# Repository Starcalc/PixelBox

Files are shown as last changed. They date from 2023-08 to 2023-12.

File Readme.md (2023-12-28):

# Pixelbox Firmware
-----

## About
Shows effects on different kind of models created with WS2812b-Stripes. The models can be simple stripes oder any rectangular shape. The configuration is done via a config.json and can be controlled via MQTT.

## Configuration
Place the configured config.json in the subdirectory "data/homie" and upload it to the device.

Sample config.json:
```json
{
"name": "nameofdevice",
"device_id": "idofdevice",
"wifi": {
"ssid": "YOURSSID",
"password": "YOURWIFIPASS"
},
"mqtt": {
"host": "your.mqtt.server",
"port": 1883,
"auth": false
},
"ota": {
"enabled": true
},
"settings": {
    "NEOPIXEL_MATRIX_NUM_ROWS": 8,
    "NEOPIXEL_MATRIX_NUM_COLUMNS": 8,
    "PIN_NEOPIXEL_MATRIX": "D2",
    "NEO_MATRIX_CONFIGURATION": "NEO_MATRIX_BOTTOM | NEO_MATRIX_RIGHT | NEO_MATRIX_ROWS | NEO_MATRIX_ZIGZAG",
    "NEO_PERMUTATION": "NEO_GRB",
    "NEO_SPEED": "NEO_KHZ800"
  }
}
```

The "settings"-part is to be configured like the Adafruit Neomatrix-Library.

PIN_NEOPIXEL_MATRIX: Which PIN the pixel data port is connected to. If you're using the ESP8266, remember NOT to use D4, as this PIN is also connected to the blue LED of the chip.

NEO_MATRIX_CONFIGURATION: The first pixel must be at one of the four corners; which corner is indicated by OR'ing either NEO_MATRIX_TOP or NEO_MATRIX_BOTTOM to either NEO_MATRIX_LEFT or NEO_MATRIX_RIGHT. The row/column arrangement is indicated by further OR'ing either NEO_MATRIX_COLUMNS or NEO_MATRIX_ROWS to either NEO_MATRIX_PROGRESSIVE or NEO_MATRIX_ZIGZAG. 

NEO_PERMUTATION: Indicate the type of LED pixels being used.

## Configuration within source code

In PixelBox.cpp on line somewhere around 35, you can configure the WIFI-Connection-capabilities of the PixelBox. If you `#define NOWIFI`, the box will rotate through some effects and will repeat them forever. 

```
#define NOWIFI // Disable WIFI alltogether
```

If you don't `#define` it (e.g. comment the line out), you can configure your WIFI and MQTT-Server in the config.json. The PixelBox will connect there and you can set the new effect by publishing to its MQTT-path.

Change the values for MQTT_HOST and "idofdevice" to the corresponding values and you can control your PixelBox via MQTT. You can easily add MQTT-commands in your [Home Assistant](https://www.home-assistant.io/) or [Node RED](https://nodered.org/).

```
mosquitto_pub -h MQTT_HOST -t "homie/idofdevice/pixel/effect/set" -m "rainbow"
```

## Features
### LED 8x8 Field
|Topic |Descriptions  |settable |Values |
|---|---|:---:|---|
|homie/`device_id`/pixel/color|Range property to set the effects colors 1 & 2 see: [effect colors](#effect-colors)|yes|Color as uint32_t see [Color](#color)|
|homie/`device_id`/pixel/brightness|Sets the brightness of the pixel strip|yes|possible values: 0 - 255|
|homie/`device_id`/pixel/effect|Set effect|yes|see: [effects](#effects)|

## Effects
### text
If the attached strips construct a rectangle, you can send scrolling text to it. The optional parameter defines the speed (interval between updates in ms) and the color.

Example: `mosquitto_pub -h HOST -t "homie/device_id/pixel/effect/set" -m "text|Hello world|100|#FF0000"`

### scanner
Shows the moving larson scanner eye known form *Battlestar Galactica* and *Knight Rider*. <!-- The used effect color can be specified by *color_0* -->

### rocket
Shows the moving larson scanner with only a trail (not an eye like `scanner`). <!-- The used effect color can be specified by *color_0* -->

### fire
If on a rectangle, shows a fireplace style fire<!--, otherwise lets all LEDs flicker somehow firelike -->.

### snow
If on a rectangle, lets snow slowly fall down from above. It melts somehow if it reaches the bottom.
<!--* **larsonspiral**
This is the same scanner then the randomscanner above but uses a spiral pattern -->
<!-- * **randomscanner**
Shows the moving larson scanner eye known form *Battlestar Galactica* and *Knight Rider*. Uses some randomness to change directions and cycles through colours. -->

### rainbowcycle
Shows a cycling rainbow on the LED strip

### theaterchase
Shows an color chasing LED strip.
<!-- You can specify the color by set *color_0* and *color_1* -->

### fade
Fades from effect color_0 to effect_color_1

<!--
### randomfade
Fades thru an alternating color pattern on all pixels with the same color.
### randomfade|40
Fades thru an alternating color pattern on all pixels with different color.
### random
Shows random static colors on all pixels differently.
-->

### smooth
Smooth changing effect.

### plasma
The all famous plasma effect known from many 8bit-Demos from the '80s and '90s.

### plasma4
The all famous plasma effect known from many 8bit-Demos from the '80s and '90s. A bit different with four calculated circles.

### heartbeat
Flashes the strip in red "a bit" like a heartbeat

### heart
On a 8x8 pixel matrix, shows a heart moving from top to bottom

### ball
Lets a ball "jump" multiple times, decreasing height. Works best on a vertical mounted strip.

### stripes
Like the `theaterchase`, but using bigger stripes following each other

<!--
### striped
?? Not working ?? -->
<!--
### stars
Multiple falling stars. Not fully implemented yet. -->
### gameoflife
Conway's game of life, only really works on a matrix

### gameoflifec
Conway's game of life like above, but colors new cells in green, dying cells in red.

### gameoflifed
Conway's game of life like above, but dims new cells (red) slowly to white if they live longer.

### snake
Auto-Play a game of snake, only really works on a matrix.

### sparkle
Randomly lets sparkles appear, looks nice on any kind of attached strip. Multiple optional parameters can be given:
interval in ms, CreationTimeout in ms, Increment as Integer, Decrement as Float

Examples:

#### static noise

`mosquitto_pub -h HOST -t "homie/device_id/pixel/effect/set" -m "sparke|1|20000|0.98"`

#### melting snowflakes

`mosquitto_pub -h HOST -t "homie/device_id/pixel/effect/set" -m "sparke|400|2|0.995"`

#### disco flash

`mosquitto_pub -h HOST -t "homie/device_id/pixel/effect/set" -m "sparke|1|3|0.1"`

#### calm

`mosquitto_pub -h HOST -t "homie/device_id/pixel/effect/set" -m "sparkle|100|1.05|0.9"`

### interval

<!-- TODO: Publish as a non-effect, but as a parameter like "brightness" -->
Changes the interval with the given parameter
`mosquitto_pub -h HOST -t "homie/device_id/pixel/effect/set" -m "100"`

### none
Stop all effects

## Effect colors
You can set to different effect colors
* *color_0* (default R: 255, G: 0  B: 0)
* *color_1* (default R: 0, G: 0  B: 255)

The effect color has to be set after the effect. <!-- Is this still true? -->
###### Example:
1. `homie/device_id/pixel/effect -m "fade"`
2. `homie/device_id/strip/color_0/set -m "255"`
3. `homie/device_id/strip/color_1/set -m "10216992"`

##### color_0
This color will be used for the following effects:
* *scanner*
* *theaterchase*
* *fade*

##### color_1
This color will be used for the following effects:
* *theaterchase*
* *fade*

## How to add another effect

The *correct* way would be to create your own Class which inherits NewMatrix(), but I guess you could just change the NewMatrix.hpp and NewMatrix.h for yourself.

* Add your string which triggers the effect to `onSetEffect()` in `PixelBox.cpp` like this:
```
  else if (command == "youreffect")
    NeoPixelMatrix.YourEffect();
  }
```
* Add your "PATTERN"-Definition in `NewMatrix.h` and increase the `LASTNEWMATRIX_PATTERN`-Counter
```
#define PATTERN_YOUREFFECT      (PATTERN_SNAKE + 13)
#define LAST_NEWMATRIX_PATTERN  (PATTERN_SNAKE + 13)
```
* Add your Update()-Call to the generic Update()-Call in `NewMatrix.hpp`:
```
case PATTERN_YOUREFFECT:
    YourPatternUpdate();
    break;
```
* Add the definition of your Pattern-Setup and Pattern-Update-Routines in `NewMatrix.h`:
```
void YourEffect();
void YourEffectUpdate();
```
* Add the code which executes your effect to `NewMatrix.hpp`:
```
void NewMatrix::YourEffect() {
    // Set up your effect, e.g. clear or define variables
    clear();
    show();
}

void NewMatrix::YourEffectUpdate() {
    show();
    lastUpdate = millis();
}
```

## List of necessary materials

Here's what you'll need:
* ESP8266 (I use the WEMOS D1 mini R2, you can easily find it on chinese selling websites)
* WS2812B-Strips with 30 LEDs/m. You'll need 64 pixels for a 8x8 Pixelbox, so at least 3 meters.
* Small wires
* Micro-USB-Power supply (5V, preferably 2A)
* Soldering equipment
* poplar wood, 4mm strong
* frosted plastic, 3-4mm strong, preferably white
* Micro-USB-Cable to connect to your PC (to transfer the initial program)

## How to build the casing

In the directory "Lasercutter" are the samples you can use for your lasercutter. You'll need one backplane, four sides all made from wood (we used poplar wood), 4mm strong. The cover should be a frosted plastic, 3-4mm strong, preferably white.

For the "pixel" effect itself you'll need to seperate the individual LEDs, so from the "trenner.dxf", you'll need 14 overall. While putting everything together remember to put the small gap in a fashion that you can place the cables, which will be connecting the LED-stripes, into these gaps.

I've added another hole where the first pixel is located to put the cables coming from the ESP8266 inside, that way the ESP8266 can be added on the backside of the pixelbox.

If you want to use a very high brightness with all LEDs showing white, the box itself will pull a lot of current (~2A), which is just about too much for the little LED stripes to handle. You'll notice that the LEDs become more and more orange/brown until the end of the strip. If you add yet another hole somewhere in the middle and add the current only there, you can neglect the effect. Remember than to add not only the "data"-cable to the ESP8266, but the GND as well.

Placing the LED-stripes I can recommend to arrange them in a "zig-zag"-manner, that way the config.json.sample will easily fit and you can add the cables between the stripes easily on one side, than on the other side.

## How to build the software

I recommend using Visual Studio Code. After successful installation, add the extension "PlatformIO" to Visual Studio Code and open the code from this repository. The "platformio.ini" is already configured for an WEMOS D1 mini R2.

If you go to the "PlatformIO"-Icon in Visual Studio Code (it's an alien skull), under "Project Tasks", you'll find these two steps, which you should execute:

* To upload the code itself: d1_mini -> General -> Upload
* To upload the config-File: d1_mini -> Platform -> Upload Filesystem Image

-----
# Thanks

A big shoutout to these people who made this Pixelbox possible:

* https://github.com/ArminJo
* https://github.com/adafruit
* https://github.com/bblanchon
* https://github.com/homieiot
* https://figch.de

And some more people from https://ctdo.de/ which either don't want to be named here or don't have a linkable presence.

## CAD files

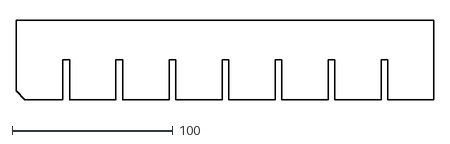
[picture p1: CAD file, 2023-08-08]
Lasercutter/trenner.dxf
259.6 x 49.6

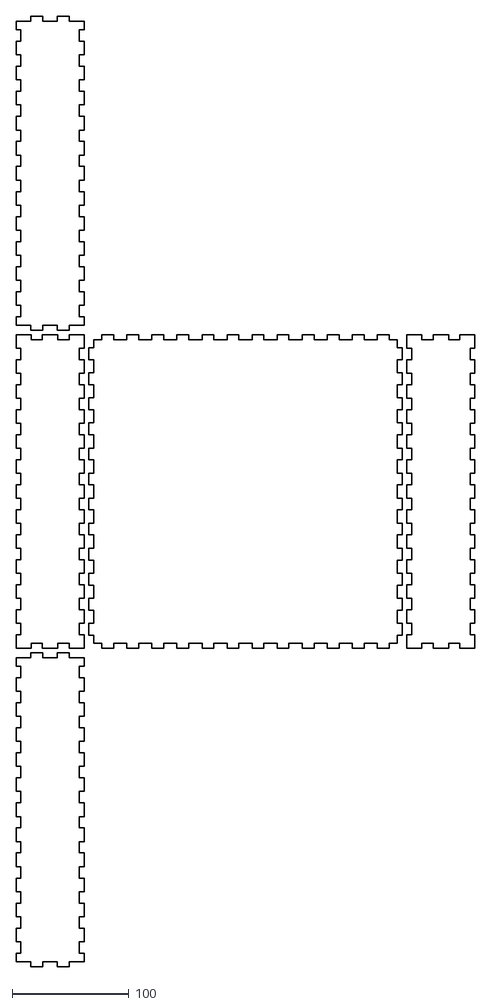
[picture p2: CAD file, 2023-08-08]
Lasercutter/box.dxf
392.6 x 812.6

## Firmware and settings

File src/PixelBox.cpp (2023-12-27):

/*
 *  PixelBox.cpp by Stefan Magerstedt
 *  Effects inspired by Armin Joachimsmeyer
 *  Uses https://github.com/ArminJo/NeoPatterns.
 *
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
 */

#define ENABLE_PATTERNS_FOR_MATRIX_AND_SNAKE_DEMO_HANDLER
#define ENABLE_PATTERNS_FOR_SNAKE_AUTORUN
#define ENABLE_PATTERN_RAINBOW_CYCLE
#define ENABLE_PATTERN_COLOR_WIPE
#define ENABLE_PATTERN_FADE
#define ENABLE_PATTERN_SCANNER_EXTENDED
#define ENABLE_PATTERN_FLASH
#define ENABLE_PATTERN_PROCESS_SELECTIVE
#define ENABLE_PATTERN_STRIPES
#define ENABLE_PATTERN_HEARTBEAT
#define ENABLE_PATTERN_BOUNCING_BALL
#define ENABLE_MATRIX_PATTERN_FIRE
#define ENABLE_MATRIX_PATTERN_SNOW

// #define NOWIFI // Disable WIFI alltogether
// #define APONLY // Disable Homie with Wifi and MQTT, but open an AP with a Web Application

#include <Arduino.h>
#include "NewMatrix.hpp"
#include "Particle.hpp"
#include "Rocket.hpp"
#include <LongUnion.h> // for faster random()
#ifndef NOWIFI
#include <ArduinoOTA.h>
#include "fixWiFi.h"
#include <Homie.h>

#else
#include <Homie/Config.hpp>
HomieInternals::Interface* homieinterface;
#endif


HomieSetting<long> rowSetting("NEOPIXEL_MATRIX_NUM_ROWS", "Rows in the matrix");
HomieSetting<long> colSetting("NEOPIXEL_MATRIX_NUM_COLUMNS", "Columns in the matrix");
HomieSetting<const char*> pinSetting("PIN_NEOPIXEL_MATRIX", "Pin connected");
HomieSetting<const char*> CONFIGURATIONSetting("NEO_MATRIX_CONFIGURATION", "Geometry CONFIGURATION");
HomieSetting<const char*> PERMUTATIONSetting("NEO_PERMUTATION", "RGB Permutation");
HomieSetting<const char*> SPEEDSetting("NEO_SPEED", "Speed of Neopixels NEO_KHZ400 or NEO_KHZ800");



/* 
    NeoPixelMatrix ist eine "NewMatrix"
    NewMatrix:: MatrixSnake:: MatrixNeoPatterns:: MatrixNeoPixel,NeoPatterns :: NeoPixel
    TODO: Alle bisherigen Effekte wieder realisieren
    TODO: Farben einbinden und entsprechend reagieren (z.B. bei Theaterchase)
    TODO: Fontgröße anpassbar machen aufgrund der jeweils genutzten Dimensionen (PROGMEM aller Fonts?!)
    TODO: Weitere Fontgrößen einbauen, in MatrixNeoPixel liegen "nur" die bis 8x8 vor.
          https://www.mikrocontroller.net/topic/54860
          Vielleicht den Font auf das FS ablegen und dann dynamisch nachladen, wenn man die Größe kennt?
          Allerdings nutzen alle Funktionen von MatrixNeoPatterns den PGM-Zugriff, um den Font zu erzeugen
    TODO: Bitmaps z.B. per MQTT erhalten und diese dann darstellen, genau wie die PGM-Varianten. Ggfs.
          muss man hierfür noch eine neue Variante bauen, die analog wie die PGM funktioniert.
*/
NewMatrix NeoPixelMatrix = NewMatrix();
char lastText[1024];
int lastinterval = 40;
uint32_t lasttextcolor = COLOR32_WHITE;
uint8_t lastbrightness = 255;

uint32_t lastUpdateCounter = 0;
uint32_t updateInterval = 1000 * 10; // 1000 * 30 = 30s
uint32_t effectCounter = 0;

bool stopAfterCompletion;
bool backup_stopAfterCompletion;
void StripComplete(NeoPatterns * aLedsPtr) {
// TODO: Wenn nicht gestoppt werden soll, soll der Effekt noch einmal angestoßen werden.
// Den letzten Effekt merken? Inklusive Aufruf? Oder jeden Effekt umschreiben, dass er ewig läuft wie z.B. Text?
  if (stopAfterCompletion)
  {
    // Next effect, repeat, etc.
  } else {
    if (NeoPixelMatrix.ActivePattern == PATTERN_TICKER) {
      NeoPixelMatrix.Ticker(lastText, lasttextcolor, COLOR32_BLACK, lastinterval, DIRECTION_LEFT);
    }
//    Serial.println("Do not stop after completion.");
  }
  return;
}

void MatrixInit()  {
  /* Lesen der Matrix-Parameter aus der config.json */
  uint8_t localpin;
  if (strcmp(pinSetting.get(), "D0") == 0) {
    localpin = D0;
  } else if (strcmp(pinSetting.get(), "D1") == 0) {
    localpin = D1;
  } else if (strcmp(pinSetting.get(), "D2") == 0) {
    localpin = D2;
  } else if (strcmp(pinSetting.get(), "D3") == 0) {
    localpin = D3;
  } else if (strcmp(pinSetting.get(), "D4") == 0) {
    localpin = D4;
  } else if (strcmp(pinSetting.get(), "D5") == 0) {
    localpin = D5;
  } else if (strcmp(pinSetting.get(), "D6") == 0) {
    localpin = D6;
  } else if (strcmp(pinSetting.get(), "D7") == 0) {
    localpin = D7;
  } else if (strcmp(pinSetting.get(), "D8") == 0) {
    localpin = D8;
  } else {
    localpin = atoi(pinSetting.get());
  }

  String confsetting = CONFIGURATIONSetting.get();
  uint8_t geometry = 0;

  Serial.println(confsetting);

// TODO: https://learn.adafruit.com/adafruit-neopixel-uberguide/neomatrix-library
//       "Other formats" mit eigener Geometrie sind möglich, da kann man auch 16bit-Integers
//       übergeben. Wenn man also in der Konfigurationsdatei irgendeinen Parameter hinterlegt,
//       dass es sich um einen Streifen handelt, könnte das wieder gehen.

  if (confsetting.indexOf("NEO_MATRIX_TOP") > -1) { geometry = geometry | NEO_MATRIX_TOP; }
  if (confsetting.indexOf("NEO_MATRIX_BOTTOM") > -1) { geometry = geometry | NEO_MATRIX_BOTTOM; }
  if (confsetting.indexOf("NEO_MATRIX_LEFT") > -1) { geometry = geometry | NEO_MATRIX_LEFT; }
  if (confsetting.indexOf("NEO_MATRIX_RIGHT") > -1) { geometry = geometry | NEO_MATRIX_RIGHT; }
  if (confsetting.indexOf("NEO_MATRIX_CORNER") > -1) { geometry = geometry | NEO_MATRIX_CORNER; }
  if (confsetting.indexOf("NEO_MATRIX_ROWS") > -1) { geometry = geometry | NEO_MATRIX_ROWS; }
  if (confsetting.indexOf("NEO_MATRIX_COLUMNS") > -1) { geometry = geometry | NEO_MATRIX_COLUMNS; }
  if (confsetting.indexOf("NEO_MATRIX_AXIS") > -1) { geometry = geometry | NEO_MATRIX_AXIS; }
  if (confsetting.indexOf("NEO_MATRIX_PROGRESSIVE") > -1) { geometry = geometry | NEO_MATRIX_PROGRESSIVE; }
  if (confsetting.indexOf("NEO_MATRIX_ZIGZAG") > -1) { geometry = geometry | NEO_MATRIX_ZIGZAG; }
  if (confsetting.indexOf("NEO_MATRIX_SEQUENCE") > -1) { geometry = geometry | NEO_MATRIX_SEQUENCE; }
  
  uint8_t permutation = 0;
  if (strcmp(PERMUTATIONSetting.get(), "NEO_RGB") == 0) { permutation = permutation | NEO_RGB; } else
  if (strcmp(PERMUTATIONSetting.get(), "NEO_RBG") == 0) { permutation = permutation | NEO_RBG; } else
  if (strcmp(PERMUTATIONSetting.get(), "NEO_GRB") == 0) { permutation = permutation | NEO_GRB; } else
  if (strcmp(PERMUTATIONSetting.get(), "NEO_GBR") == 0) { permutation = permutation | NEO_GBR; } else
  if (strcmp(PERMUTATIONSetting.get(), "NEO_BRG") == 0) { permutation = permutation | NEO_BRG; } else
  if (strcmp(PERMUTATIONSetting.get(), "NEO_BGR") == 0) { permutation = permutation | NEO_BGR; } else
  if (strcmp(PERMUTATIONSetting.get(), "NEO_WRGB") == 0) { permutation = permutation | NEO_WRGB; } else
  if (strcmp(PERMUTATIONSetting.get(), "NEO_WRBG") == 0) { permutation = permutation | NEO_WRBG; } else
  if (strcmp(PERMUTATIONSetting.get(), "NEO_WGRB") == 0) { permutation = permutation | NEO_WGRB; } else
  if (strcmp(PERMUTATIONSetting.get(), "NEO_WGBR") == 0) { permutation = permutation | NEO_WGBR; } else
  if (strcmp(PERMUTATIONSetting.get(), "NEO_WBRG") == 0) { permutation = permutation | NEO_WBRG; } else
  if (strcmp(PERMUTATIONSetting.get(), "NEO_WBGR") == 0) { permutation = permutation | NEO_WBGR; } else
  if (strcmp(PERMUTATIONSetting.get(), "NEO_RWGB") == 0) { permutation = permutation | NEO_RWGB; } else
  if (strcmp(PERMUTATIONSetting.get(), "NEO_RWBG") == 0) { permutation = permutation | NEO_RWBG; } else
  if (strcmp(PERMUTATIONSetting.get(), "NEO_RGWB") == 0) { permutation = permutation | NEO_RGWB; } else
  if (strcmp(PERMUTATIONSetting.get(), "NEO_RGBW") == 0) { permutation = permutation | NEO_RGBW; } else
  if (strcmp(PERMUTATIONSetting.get(), "NEO_RBWG") == 0) { permutation = permutation | NEO_RBWG; } else
  if (strcmp(PERMUTATIONSetting.get(), "NEO_RBGW") == 0) { permutation = permutation | NEO_RBGW; } else
  if (strcmp(PERMUTATIONSetting.get(), "NEO_GWRB") == 0) { permutation = permutation | NEO_GWRB; } else
  if (strcmp(PERMUTATIONSetting.get(), "NEO_GWBR") == 0) { permutation = permutation | NEO_GWBR; } else
  if (strcmp(PERMUTATIONSetting.get(), "NEO_GRWB") == 0) { permutation = permutation | NEO_GRWB; } else
  if (strcmp(PERMUTATIONSetting.get(), "NEO_GRBW") == 0) { permutation = permutation | NEO_GRBW; } else
  if (strcmp(PERMUTATIONSetting.get(), "NEO_GBWR") == 0) { permutation = permutation | NEO_GBWR; } else
  if (strcmp(PERMUTATIONSetting.get(), "NEO_GBRW") == 0) { permutation = permutation | NEO_GBRW; } else
  if (strcmp(PERMUTATIONSetting.get(), "NEO_BWRG") == 0) { permutation = permutation | NEO_BWRG; } else
  if (strcmp(PERMUTATIONSetting.get(), "NEO_BWGR") == 0) { permutation = permutation | NEO_BWGR; } else
  if (strcmp(PERMUTATIONSetting.get(), "NEO_BRWG") == 0) { permutation = permutation | NEO_BRWG; } else
  if (strcmp(PERMUTATIONSetting.get(), "NEO_BRGW") == 0) { permutation = permutation | NEO_BRGW; } else
  if (strcmp(PERMUTATIONSetting.get(), "NEO_BGWR") == 0) { permutation = permutation | NEO_BGWR; } else
  if (strcmp(PERMUTATIONSetting.get(), "NEO_BGRW") == 0) { permutation = permutation | NEO_BGRW; }

  if (strcmp(SPEEDSetting.get(), "NEO_KHZ400") == 0) { permutation = permutation | NEO_KHZ400; } else
  if (strcmp(SPEEDSetting.get(), "NEO_KHZ800") == 0) { permutation = permutation | NEO_KHZ800; } 

  NeoPixelMatrix.init(colSetting.get(), rowSetting.get(), localpin, geometry, permutation, &StripComplete);
}

#ifndef NOWIFI
HomieNode homieNode("pixel", "pixel", "commands");
#endif

bool onSetReverse(const HomieRange & range, const String & value) {
  NeoPixelMatrix.Reverse();
#ifndef NOWIFI
  homieNode.setProperty("reverse").send(value);
#endif
  return true;
}

bool onSetBrightness(const HomieRange& range, const String& value) {
	long brightness = value.toInt();
	if (brightness < 0 || brightness > 255) {
		return false;
	}
	NeoPixelMatrix.setBrightnessValue(brightness);
#ifndef NOWIFI
	homieNode.setProperty("brightness").send(value);
#endif
	return true;
}

bool is_number(String s)
{
  uint16_t Numbers = 0;
  for(uint16_t i = 0; i < s.length(); i++)
  {
    if (s[i] >= '0' && s[i] <= '9')
    {
      Numbers ++;
    }
  }
  if (Numbers == s.length())
  { return true; } else { return false; }
}

uint32_t parseColor(String value) {
  if (value.charAt(0) == '#') { //solid fill
    String color = value.substring(1);
    int number = (int) strtol( &color[0], NULL, 16);
    // Split them up into r, g, b values
    int r = number >> 16;
    int g = number >> 8 & 0xFF;
    int b = number & 0xFF;
    return COLOR32(r, g, b);
  }
  return 0;
}

bool onSetColor0(const HomieRange& range, const String& value) {
  if (value.charAt(0) == '#') {
    NeoPixelMatrix.SetColor1(parseColor(value));
  } else {
    if (!is_number(value)) return false;
    NeoPixelMatrix.SetColor1(value.toInt());
  }
#ifndef NOWIFI
  homieNode.setProperty("color0").setRange(range).send(value);
#endif
  //homieNode.setProperty("color_" + String(range.index)).send(value);
  return true;
}

bool onSetColor1(const HomieRange& range, const String& value) {
  if (value.charAt(0) == '#') {
    NeoPixelMatrix.SetColor2(parseColor(value));
  } else {
    if (!is_number(value)) return false;
    NeoPixelMatrix.SetColor2(value.toInt());
  }
#ifndef NOWIFI
  homieNode.setProperty("color1").setRange(range).send(value);
#endif
  //homieNode.setProperty("color_" + String(range.index)).send(value);
  return true;
}

/***
 * Effektidee: Zwei farbliche "Masken" (veränderbar) für die Darstellung des Textes. Dabei wird die eine für den
 * Hintergrund genutzt, die andere für den eigentlichen Text. So sind dynamische Regenbogenschriftarten möglich,
 * auch innerhalb eines Buchstabens. Oder sogar schneller wechselnd als der Text? (Mit einem zweiten Interval?)
 * 
 * TODO: Randomscanner, rainbowtext, Colors @ rocket and scanner, fire (for flat stripes like in RGB5m), random, randomfade, stars, moving picture (given by MQTT or UDP or...? - maybe store it on the SPIFFS, if possible)
 * aLedsPtr->Stripes(NeoPatterns::Wheel(tColor), 1, NeoPatterns::Wheel(tColor + 0x80), 2, 2 * aLedsPtr->numPixels(),
                tDuration * 2, (tColor & DIRECTION_DOWN));
***/
bool onSetEffect(const HomieRange& range, const String& value) {
  Serial.println(value);
  LongUnion tRandom;
  tRandom.Long = random();
  uint8_t tColor = tRandom.UBytes[1];
  uint8_t tDuration = ((tRandom.UBytes[1] * (80 - 40)) >> 8) + 40;
  NeoPixelMatrix.OnPatternComplete = &StripComplete;
  stopAfterCompletion = false;
  int validparams = 0;
  int sep = value.indexOf("|");
  String param1, param2, param3, param4;
  String command = value;
  if (sep > 0)
  {
    // Parameter given
    command = value.substring(0, sep);
    String parameters = value.substring(sep + 1);
    param1 = parameters;
    validparams = 1;
    int sep2 = parameters.indexOf("|");
    if (sep2 > 0) {
      // Es gibt mindestens zwei Parameter
      param1 = parameters.substring(0, sep2);
      parameters = parameters.substring(sep2 + 1);
      param2 = parameters;
      validparams = 2;
      int sep3 = parameters.indexOf("|");
      if (sep3 > 0)
      {
        // Es gibt mindestens drei Parameter
        param2 = parameters.substring(0, sep3);
        parameters = parameters.substring(sep3 + 1);
        param3 = parameters;
        validparams = 3;
        int sep4 = parameters.indexOf("|");
        if (sep4 > 0)
        {
          // Es gibt mindestens vier Parameter
          param3 = parameters.substring(0, sep4);
          param4 = parameters.substring(sep4 + 1);
          validparams = 4;
        }
      }
    }
  }
	if (command == "text") {
    String stext;
    int interval = 40;
    uint32_t textcolor = COLOR32_WHITE;
    switch (validparams) {
          case 0:
            stext = "(No text given)";
            break;
          case 1:
            stext = param1;
            break;
          case 2:
            stext = param1;
            interval = param2.toInt();
            break;
          case 3:
            stext = param1;
            interval = param2.toInt();
            textcolor = parseColor(param3);
            break;
        }
    lastinterval = interval;
    lasttextcolor = textcolor;
    strncpy(lastText, stext.c_str(), (strlen(stext.c_str())>1022) ? 1022 : strlen(stext.c_str()));
    lastText[strlen(stext.c_str())] = 0;
#ifndef NOWIFI
    homieNode.setProperty("scrollinfo").send("Scroll " + stext + " with interval " + String(interval) + " and color " + String(textcolor));
#endif
    // TODO: Color1 und Color2 verwenden, wie eingestellt?
    NeoPixelMatrix.Ticker(lastText, textcolor, COLOR32_BLACK, interval, DIRECTION_LEFT);
	}
  else if (command == "scanner") {
      NeoPixelMatrix.infinite_repetitions = true;
      NeoPixelMatrix.ScannerExtended(NeoPixelMatrix.Color(255,0,0), 5, 40, 2, FLAG_SCANNER_EXT_CYLON);
   }
  else if (command == "rocket") {
      NeoPixelMatrix.infinite_repetitions = true;
      NeoPixelMatrix.ScannerExtended(NeoPixelMatrix.Color(255,0,0), 5, 40, 2, FLAG_SCANNER_EXT_ROCKET);
  }
  else if (command == "none" || command == "off") {
    NeoPixelMatrix.infinite_repetitions = false;
    NeoPixelMatrix.None();
  }
  else if (command == "snow") {
    NeoPixelMatrix.infinite_repetitions = true;
    NeoPixelMatrix.Snow();
  }
  else if (command == "randomscanner") {
    // TODO: Randomscanner
  //   strip.Scanner(strip.Color(255, 0, 0), 40, true);
  }
  else if (command == "larsonspiral") {
    // TODO: Larsonspiral
  //   strip.Scanner(strip.Color(255, 0, 0), 40, true, true);
  }
  else if (command == "rainbowcycle") {
    NeoPixelMatrix.infinite_repetitions = true;
    NeoPixelMatrix.RainbowCycle(20, DIRECTION_DOWN);
  }
  else if (command == "theaterchase" || command == "chase") {
    /* TODO: Auf gesetzte Farben reagieren */
    // NeoPixelMatrix.SetColor1(value.toInt());
    NeoPixelMatrix.Stripes(NeoPatterns::Wheel(tColor), 1, NeoPatterns::Wheel(tColor + 0x80), 2, 2 * NeoPixelMatrix.numPixels(),
              tDuration * 2, (tColor & DIRECTION_DOWN));
  }
  else if (command == "fade") {
    // TODO: Instable
    NeoPixelMatrix.infinite_repetitions = true;
    NeoPixelMatrix.Fade(NeoPatterns::Wheel(tColor), NeoPatterns::Wheel(tColor + 0x80), 1000, 1);
  //   strip.Fade(strip.Color(255, 0, 0), strip.Color(0, 0, 255), 200, 100);
  }
  else if (command == "randomfade") {
  //   strip.RandomFade();
  }
  else if (command == "random") {
  //   strip.Random();
  }
  else if (command == "smooth") { //example: smooth|[wheelspeed]|[smoothing]|[strength]     wheelspeed=1-255, smoothing=0-100, strength=1-255
  //   strip.Smooth(16, 80, 50, 40);
    NeoPixelMatrix.Smooth(16, 80, 50, 40);
  }
  else if (command == "plasma") {
      NeoPixelMatrix.Plasma();
  }
  else if (command == "plasma4") {
      NeoPixelMatrix.Plasma4();
  }
	else if (command == "heartbeat") {
    NeoPixelMatrix.infinite_repetitions = true;
    NeoPixelMatrix.Heartbeat(NeoPixelMatrix.Color(255,0,0), 20 , 0 , 0);
	}
	else if (command == "heart") {
    NeoPixelMatrix.MovingPicturePGM(heart8x8, COLOR32_RED_HALF, COLOR32_BLACK, 0, -1, 100, 100, DIRECTION_DOWN);
	}
	else if (command == "ball") {
    NeoPixelMatrix.BouncingBall(NeoPatterns::Wheel(tColor), NeoPixelMatrix.numPixels() - 1);
	}
	else if (command == "stripes") {
    // NeoPixelMatrix.Direction = DIRECTION_DOWN;
    NeoPixelMatrix.infinite_repetitions = true;
    NeoPixelMatrix.Stripes(NeoPixelMatrix.Color1, 5, NeoPixelMatrix.LongValue1.Color2, 1, 2 * NeoPixelMatrix.numPixels(), tDuration * 2, (tColor & DIRECTION_DOWN));
	}
	else if (command == "striped") {
    // TODO: Test me!
    NeoPixelMatrix.infinite_repetitions = true;
    NeoPixelMatrix.StripesD(NeoPatterns::Wheel(tColor), 5, NeoPatterns::Wheel(tColor + 0x80), 3, 2 * NeoPixelMatrix.numPixels(),
                tDuration * 2, (tColor & DIRECTION_DOWN));
	}
  else if (command == "stars") {
    // NeoPixelMatrix.initMultipleFallingStars(aLedsPtr, COLOR32_WHITE_HALF, 7, tDuration, 3, &allPatternsRandomHandler);
  }
  else if (command == "gameoflife") {
    switch (validparams) {
        case 0:
          // homieNode.setProperty("gameoflifeinfo").send("GameOfLife with interval " + String(1000) + " and count " + String(32));
          NeoPixelMatrix.GameOfLife(250, 32);
          break;
        case 1:
#ifndef NOWIFI
          homieNode.setProperty("gameoflifeinfo").send("GameOfLife with " + String(param1));
#endif
          NeoPixelMatrix.GameOfLife(250, 32, false, param1);
          break;
    }
  }
  else if (command == "gameoflifec") {
    switch (validparams) {
        case 0:
          NeoPixelMatrix.GameOfLife(250, 32, true);
          break;
        case 1:
#ifndef NOWIFI
          homieNode.setProperty("gameoflifecinfo").send("GameOfLife with " + String(param1));
#endif
          NeoPixelMatrix.GameOfLife(250, 32, true, param1);
          break;
    }
  }
  else if (command == "gameoflifed") {
    switch (validparams) {
        case 0:
          NeoPixelMatrix.GameOfLife(250, 32, false, "", true);
          break;
        case 1:
#ifndef NOWIFI
          homieNode.setProperty("gameoflifedinfo").send("GameOfLifeDim with " + String(param1));
#endif
          NeoPixelMatrix.GameOfLife(250, 32, false, param1, true);
          break;
    }
  }
  else if (command == "snake") {
    NeoPixelMatrix.OnPatternComplete = &SnakeAutorunCompleteHandler;
    initSnakeAutorun(&NeoPixelMatrix, 200, COLOR32_BLUE, 5);
  }
  else if (command == "randomfill")
  { 
    // Fills "slowly" all pixels with a random colour
    // 21 hell, 9 dunkel  (-1, +1)
    // bei   "NEOPIXEL_MATRIX_NUM_ROWS": 20,
    // und   "NEOPIXEL_MATRIX_NUM_COLUMNS": 30,
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
void loop() {

#ifndef NOWIFI
  Homie.loop();
  fixWiFi();
  ArduinoOTA.handle();
#else

  if ((millis() - lastUpdateCounter) > updateInterval) {
    effectCounter++;
    Serial.println(effectCounter);
    switch (effectCounter%16) {
      case 0:
        onSetEffect(HomieRange(), "scanner");
        break;
      case 1:
        onSetEffect(HomieRange(), "text|Welcome Pixelbox");
        break;
      case 2:
        onSetEffect(HomieRange(), "plasma");
        break;
      case 3:
        onSetEffect(HomieRange(), "gameoflifec");
        break;
      case 4:
        onSetEffect(HomieRange(), "snow");
        break;
      case 5:
        onSetEffect(HomieRange(), "sparkle");
        break;
      case 6:
        onSetEffect(HomieRange(), "snake");
        break;
      case 7:
        onSetEffect(HomieRange(), "rainbowcycle");
        break;
      case 8:
        onSetEffect(HomieRange(), "theaterchase");
        break;
      case 9:
        onSetEffect(HomieRange(), "fire");
        break;
      case 10:
        onSetInterval(HomieRange(), "200");
        onSetEffect(HomieRange(), "smooth"); //example: smooth|[wheelspeed]|[smoothing]|[strength] wheelspeed=1-255, smoothing=0-100, strength=1-255
        break;
      case 11:
        onSetEffect(HomieRange(), "heartbeat"); // Looks nicer on a singular strip
        break;
      case 12:
        onSetEffect(HomieRange(), "heart");
        break;
      case 13:
        onSetEffect(HomieRange(), "ball"); // Looks nicer on a singular strip
        break;
      case 14:
        onSetEffect(HomieRange(), "plasma4");
        break;
      case 15:
        onSetEffect(HomieRange(), "gameoflife"); 
        break;
    }

    
    lastUpdateCounter = millis();
  }

#endif
  // if ((millis() - heaptick) > 1000) {
  //   Homie.getLogger() << ESP.getFreeHeap() << endl;
  //   heaptick = millis();
  // }
	if (NeoPixelMatrix.update()) { 
		// if (NeoPixelMatrix.ActivePattern == PATTERN_TICKER) {
		// 	// change color of ticker after each update
		// 	NeoPixelMatrix.Color1 = NeoPatterns::Wheel(sWheelPosition);
		// 	sWheelPosition += 256 / NEOPIXEL_MATRIX_NUM_PIXELS;
		// }
	}
}

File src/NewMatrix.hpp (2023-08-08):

#ifndef NEWMATRIX_HPP_
#define NEWMATRIX_HPP_
#include "NewMatrix.h"
//#include "Particle.hpp"
NewMatrix::NewMatrix() : // @suppress("Class members should be properly initialized")
        NeoPixel(), MatrixSnake() {
}

/* TODO: Clear, if effect has finished */

// Constructor - calls base-class constructor to initialize strip
NewMatrix::NewMatrix(uint8_t aColumns, uint8_t aRows, uint8_t aPin, uint8_t aMatrixGeometry, uint8_t aTypeOfPixel, // @suppress("Class members should be properly initialized")
  void (*aPatternCompletionCallback)(NeoPatterns*)) :
  NeoPixel(aColumns * aRows, aPin, aTypeOfPixel), MatrixSnake(aColumns, aRows, aPin, aMatrixGeometry, aTypeOfPixel,
    aPatternCompletionCallback) {}

bool NewMatrix::init(uint8_t aColumns, uint8_t aRows, uint8_t aPin, uint8_t aMatrixGeometry, uint8_t aTypeOfPixel,
        void (*aPatternCompletionCallback)(NeoPatterns*)) {
  // Für den Smooth-Effekt
  // Allocate a zero initialized block of memory big enough to hold "pixels" uint8_t.
    pixelR = ( uint8_t* ) calloc( aColumns * aRows, sizeof( uint8_t ) );
    pixelG = ( uint8_t* ) calloc( aColumns * aRows, sizeof( uint8_t ) );
    pixelB = ( uint8_t* ) calloc( aColumns * aRows, sizeof( uint8_t ) );
    pixelR_buffer = ( uint8_t* ) calloc( aColumns * aRows, sizeof( uint8_t ) );
    pixelG_buffer = ( uint8_t* ) calloc( aColumns * aRows, sizeof( uint8_t ) );
    pixelB_buffer = ( uint8_t* ) calloc( aColumns * aRows, sizeof( uint8_t ) );          
    NeoPixel::init(aColumns * aRows, aPin, aTypeOfPixel);
    return MatrixSnake::init(aColumns, aRows, aPin, aMatrixGeometry, aTypeOfPixel, aPatternCompletionCallback);
}


/* Additional routines, missing in original Matrix */
void NewMatrix::fillw(uint32_t c, uint8_t w, uint16_t first, uint16_t count) {
  uint16_t i, end;

  if (first >= numLEDs) {
    return; // If first LED is past end of strip, nothing to do
  }

  // Calculate the index ONE AFTER the last pixel to fill
  if (count == 0) {
    // Fill to end of strip
    end = numLEDs;
  } else {
    // Ensure that the loop won't go past the last pixel
    end = first + count;
    if (end > numLEDs)
      end = numLEDs;
  }

  for (i = first; i < end; i++) {
    // setPixelColor(uint16_t n, uint8_t r, uint8_t g, uint8_t b, uint8_t w)
    uint8_t r = (uint8_t)(c >> 16), g = (uint8_t)(c >> 8), b = (uint8_t)c;
    this->setPixelColor(i, r, g, b, w);
  }
}

void NewMatrix::setMatrixPixelColorw(uint8_t aColumnX, uint8_t aRowY, uint8_t aRed, uint8_t aGreen, uint8_t aBlue, uint8_t aWhite) {
    if (aColumnX < Columns && aRowY < Rows) {
#ifdef TRACE
        printPin();
        Serial.print(F("set x="));
        Serial.print(aColumnX);
        Serial.print(F(" y="));
        Serial.print(aRowY);
        Serial.print(F(" n="));
        Serial.print(LayoutMapping(aColumnX, aRowY));
        Serial.print(F(" Color="));
        Serial.print(aRed);
        Serial.print('|');
        Serial.print(aGreen);
        Serial.print('|');
        Serial.println(aBlue);
#endif
#ifndef SUPPORT_ONLY_DEFAULT_GEOMETRY
        if (LayoutMappingFunction == NULL) {
            setPixelColor(LayoutMapping(aColumnX, aRowY), aRed, aGreen, aBlue, aWhite);
        } else {
            setPixelColor(LayoutMappingFunction(aColumnX, aRowY, Columns, Rows), aRed, aGreen, aBlue, aWhite);
        }
#else
    setPixelColor((Columns * (Rows - aRowY) - aColumnX) - 1, aRed, aGreen, aBlue);
#endif
#ifdef TRACE
    } else {
        printPin();
        Serial.print(F("skip x="));
        Serial.print(aColumnX);
        Serial.print(F(" y="));
        Serial.println(aRowY);
#endif
    }
}

/*
 * Update the pattern.
 * Returns true if update has really happened in order to give the caller a chance to manually change parameters after each update (like color etc.)
 * Calls snake input handler and after each interval calls snake update routine or MatrixNeoPatterns::Update().
 */
bool NewMatrix::update() {

    if ((millis() - lastUpdate) > Interval) {
        // time to update
        if (infinite_repetitions) { TotalStepCounter = 256; }
        switch (ActivePattern)
        {
            case PATTERN_PLASMA:
                PlasmaUpdate();
                break;
            case PATTERN_PLASMA4:
                Plasma4Update();
                break;
            case PATTERN_SMOOTH:
                SmoothUpdate();
                break;
            case PATTERN_SPARKLE:
                SparkleUpdate();
                break;
            case PATTERN_GAMEOFLIFE:
                GameOfLifeUpdate();
                break;
            case PATTERN_FIREFLAT:
                FireFlatUpdate();
                break;
            case PATTERN_FIREWORKS:
                FireworksUpdate();
                break;
            case PATTERN_DROP:
                DropUpdate();
                break;
            case PATTERN_RING:
                RingsUpdate();
                break;
            case PATTERN_FILL:
                FillUpdate();
                break;
            case PATTERN_SPARKLEW:
                SparklewUpdate();
                break;
            case PATTERN_RANDOMFILL:
                RandomFillUpdate();
                break;
            default:
                MatrixSnake::update();
                break;
        }
        return true;
    }
    return false;
}

void NewMatrix::SetInterval(uint8_t interval) {
  Interval = interval;
}

void NewMatrix::Reverse() {
  Direction = ((Direction+2)&2);
}


/****************** Plasma ******************/

// Based upon https://github.com/johncarl81/neopixelplasma
void NewMatrix::Plasma(float phase, float phaseIncrement, float colorStretch, uint8_t interval)
{
  ActivePattern = PATTERN_PLASMA;
  Interval = interval;
  PlasmaPhase = phase;
  PlasmaPhaseIncrement = phaseIncrement;
  PlasmaColorStretch = colorStretch;
}
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

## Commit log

2023-08-08 Cleanup for github
    [trenner kabelfuehrung.dxf, trenner.dxf]
2023-08-17 Consistent config.json.sample with readme

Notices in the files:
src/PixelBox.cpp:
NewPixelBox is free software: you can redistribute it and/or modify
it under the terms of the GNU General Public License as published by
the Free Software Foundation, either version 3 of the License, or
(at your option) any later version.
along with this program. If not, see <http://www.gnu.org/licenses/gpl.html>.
